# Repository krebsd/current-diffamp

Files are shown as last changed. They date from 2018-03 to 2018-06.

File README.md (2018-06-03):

# Differential current sense Amplifier - current-diffamp

Differential Amplifier circuit for use in current sensing applications. The circuit is designed to be used in conjunction with an oscilloscope.

## PREFACE
This project and especially its documentation including this README is still in a very early state of development. This document will be updated with further information in the future.

## EDA

* [KiCad](http://kicad-pcb.org) - KiCad EDA is used for the PCB design

## Authors

* **David Krebs** - *Initial work* - [krebsd](https://github.com/krebsd)

## License

<br />This work is licensed under a <a rel="license" href="http://creativecommons.org/licenses/by-sa/4.0/">Creative Commons Attribution-ShareAlike 4.0 International License</a>

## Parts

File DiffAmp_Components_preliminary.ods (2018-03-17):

Reference | Value | Part | Part No | Distributor | Distributor Part No
C1 | 10u | C Radial 10 uF 50V D5.0mm_P2.00mm |  | Reichelt | FR-A 10U 50
C2 | 100n | C 0805 100n
C3 | 100u | C Radial 100 uF 50V D8.0mm_P3.50mm |  | Reichelt | RAD FR 100/50
C4 | 100u | C Radial 100 uF 50V D8.0mm_P3.50mm |  | Reichelt | RAD FR 100/50
C5 | 10u | C 1210 X5R 10u 50V | UMK325AB7106MM-T | Digikey | 587-3166-1-ND
C6 | 10u | C 1210 X5R 10u 50V | UMK325AB7106MM-T | Digikey | 587-3166-1-ND
C7 | 10n | C 0805 10n |  | Reichelt
C8 | 10n | C 0805 10n
C9 | 10n | C 0805 10n
C10 | 10n | C 0805 10n
C11 | 10u | C 1210 X5R 10u 50V | UMK325AB7106MM-T | Digikey | 587-3166-1-ND
C12 | 10u | C 1210 X5R 10u 50V | UMK325AB7106MM-T | Digikey | 587-3166-1-ND
C13 | 10n | C 0805 10n
C14 | 100n | C 0805 100n
C15 | C | C 0805
C16 | C | C 0805
C17 | C | C 0805
C18 | C | C 0805
C19 | C | C 0805
C20 | C | C 0805
C21 | C_Variable | Murata TZC3 |  | Reichelt | TZC03 XXP | exact part tbd
C22 | C_Variable | Murata TZC3 |  | Reichelt | TZC03 XXP | exact part tbd
C23 | C | C 0805
C24 | C | C 0805
C25 | C | C 0805
C26 | 100n | C 0805 100n
C27 | 100n | C 0805 100n
C28 | 100n | C 0805 100n
C29 | C | C 0805
C30 | 10p | C 0805 10p
C31 | 100n | C 0805 100n
C32 | 100n | C 0805 100n
C33 | 100n | C 0805 100n
C34 | C | C 0805
C35 | 10p | C 0805 10p
C36 | 100n | C 0805 100n
C37 | 100n | C 0805 100n
C38 | 100n | C 0805 100n
C39 | C | C 0805
D1 | CMPD6001S | CMPD6001S – SOT-23 | CMPD6001S TR | Digikey | CMPD6001SCT-ND
D2 | CMPD6001S | CMPD6001S – SOT-23 | CMPD6001S TR | Digikey | CMPD6001SCT-ND
D3 | CMPD6001S | CMPD6001S – SOT-23 | CMPD6001S TR | Digikey | CMPD6001SCT-ND
D4 | CMPD6001S | CMPD6001S – SOT-23 | CMPD6001S TR | Digikey | CMPD6001SCT-ND
F1 | PFRA050 | Polyfuse PFRA 050 |  | Reichelt | PFRA 050
J1 | USB_OTG | USB Micro B |  | Reichelt | MIC USB BBU
J2 | Screw_Terminal_1x03 | AKL 057-03 |  | Reichelt | AKL 057-03
J3 | Conn_01x02 | Pin Header 1x2 |  | Reichelt
J4 | Conn_01x02 | Pin Header 1x2
J5 | Conn_01x02 | Pin Header 1x2
JP1 | Jumper_NO_Small | Pin Header 1x2
JP2 | Jumper | Pin Header 1x2
JP3 | Jumper_NC_Dual | Pin Header 1x3
JP4 | Jumper | Pin Header 1x2
JP5 | Jumper | Pin Header 1x2
JP6 | Jumper_NC_Dual | Pin Header 1x3
JP7 | Jumper_NC_Dual | Pin Header 1x3
JP8 | Jumper_NO | Pin Header 1x2
R1 | 130k | R 0805 130k 1% |  | Reichelt
R2 | 10k | R 0805 10k 1%
R3 | 10k | R 0805 10k 1%
R4 | 130k | R 0805 130k 1% |  | Reichelt
R5 | 0 | R 0805 0
R6 | 1k | R 0805 1k 1%
R7 | 10k | R 0805 10k 1%
R8 | 10k | R 0805 10k 1%
R9 | 22 | R 0805 22 1%
R10 | Y14870R10000B9W | CSM2512 – 0R1 0,1% | Y14870R10000B9W | Digikey | Y1487-.1-ND
R11 | 3M9 | R 0805 3M9 0,1% |  | Reichelt |  | Testing with 1%!
R12 | 3M9 | R 0805 3M9 0,1% |  | Reichelt |  | Testing with 1%!
R13 | 3M9 | R 0805 3M9 0,1% |  | Reichelt |  | Testing with 1%!
R14 | 3M9 | R 0805 3M9 0,1% |  | Reichelt |  | Testing with 1%!
R15 | 1M2 | R 0805 1M2 0,1% |  | Reichelt |  | Testing with 1%!
R16 | 1M2 | R 0805 1M2 0,1% |  | Reichelt |  | Testing with 1%!
R17 | 1M0 | R 0805 1M0 0,1% |  | Reichelt |  | Testing with 1%!
R18 | 1M0 | R 0805 1M0 0,1% |  | Reichelt |  | Testing with 1%!
R19 | 249 | R 0805 249 1% |  | Reichelt
R20 | 249 | R 0805 249 1% |  | Reichelt
R21 | 249 | R 0805 249 1% |  | Reichelt
R22 | 249 | R 0805 249 1% |  | Reichelt
R23 | 249 | R 0805 249 1% |  | Reichelt
R24 | 249 | R 0805 249 1% |  | Reichelt
R25 | 249 | R 0805 249 1% |  | Reichelt
R26 | 249 | R 0805 249 1% |  | Reichelt
R27 | 100 | R 0805 100 0,05% | RG2012N-101-W-T1 | Digikey | RG20N100WCT-ND
R28 | 1k | R 0805 1k 0,05% | ERA-6ARW102V | Digikey | P1.0KBSCT-ND
R29 | 0 | R 0805 0
R30 | 47 | R 2512 47 | RC2512JK-0747RL | Digikey | YAG3404CT-ND
R31 | R | R 0805
R32 | 1k0 | R 0805 1k 0,05% | ERA-6ARW102V | Digikey | P1.0KBSCT-ND
R33 | 6k8 | R 0805 6k8 0,05% | ERA-6ARW682V | Digikey | P6.8KBSCT-ND
R34 | 0 | R 0805 0
R35 | 2k2 | R 0805 2k2 0,05% | ERA-6ARW222V | Digikey | P2.2KBSCT-ND
R36 | 47 | R 2512 47 | RC2512JK-0747RL | Digikey | YAG3404CT-ND
R37 | R | R 0805
R38 | 1k0 | R 0805 1k 0,05% | ERA-6ARW102V | Digikey | P1.0KBSCT-ND
R39 | 6k8 | R 0805 6k8 0,05% | ERA-6ARW682V | Digikey | P6.8KBSCT-ND
R40 | 0 | R 0805 0
R41 | 2k2 | R 0805 2k2 0,05% | ERA-6ARW222V | Digikey | P2.2KBSCT-ND
R42 | 47 | R 2512 47 | RC2512JK-0747RL | Digikey | YAG3404CT-ND
R43 | R | R 0805
U1 | SF_IHXXXXS | DC DC Converter SF IH0524S | IH0524SH | Digikey | 1470-1446-5-ND
U2 | TPS7A49 | Linear Regulator positive TPS7A49 |  | Reichelt | TPS 7A4901DGNT
U3 | TPS7A30 | Linear Regulator negative TPS7A30 |  | Reichelt | TPS 7A3001DGNT
U4 | OPA189 | OPAmp OPA189 | OPA189ID | Digikey | 296-47522-ND
U5 | AD8421 | Differential Amplifier AD8421BRZ | AD8421BRZ | Digikey | AD8421BRZ-R7CT-ND
U6 | OPA189 | OPAmp OPA189 | OPA189ID | Digikey | 296-47522-ND
U7 | OPA189 | OPAmp OPA189 | OPA189ID | Digikey | 296-47522-ND

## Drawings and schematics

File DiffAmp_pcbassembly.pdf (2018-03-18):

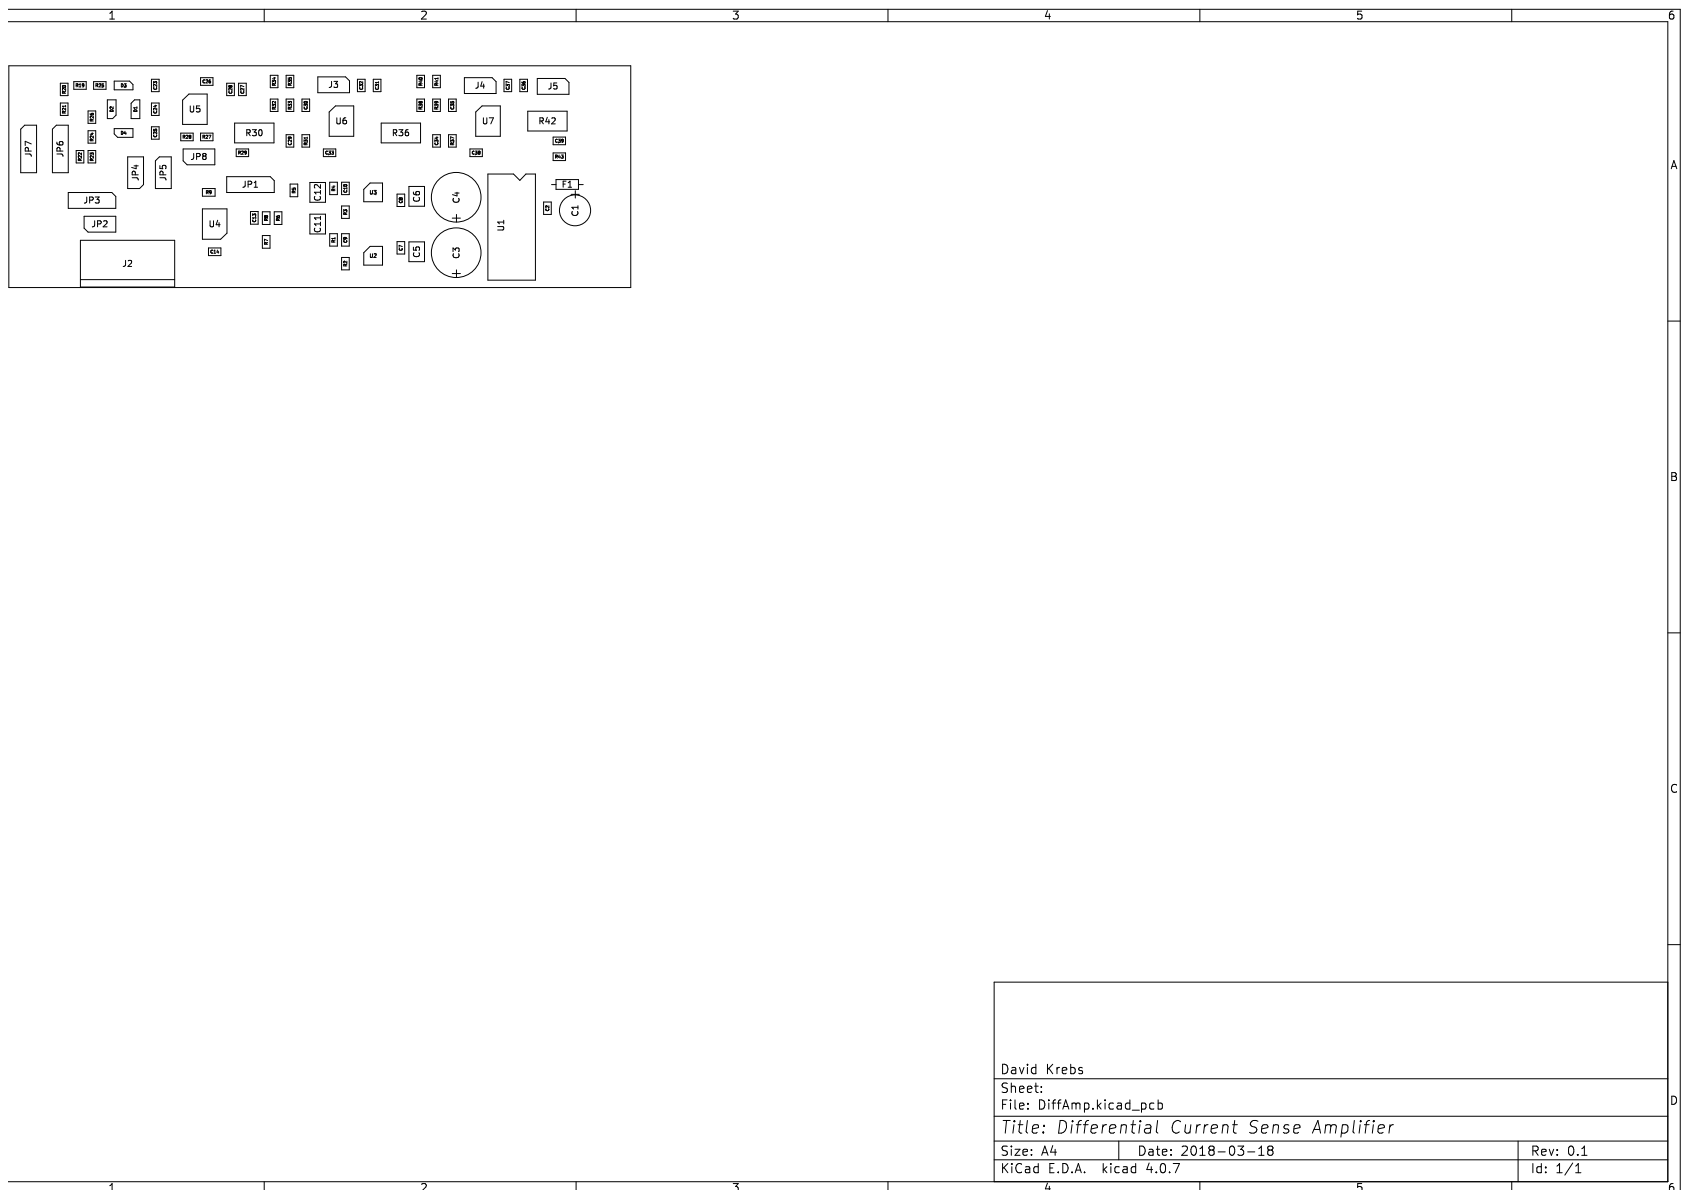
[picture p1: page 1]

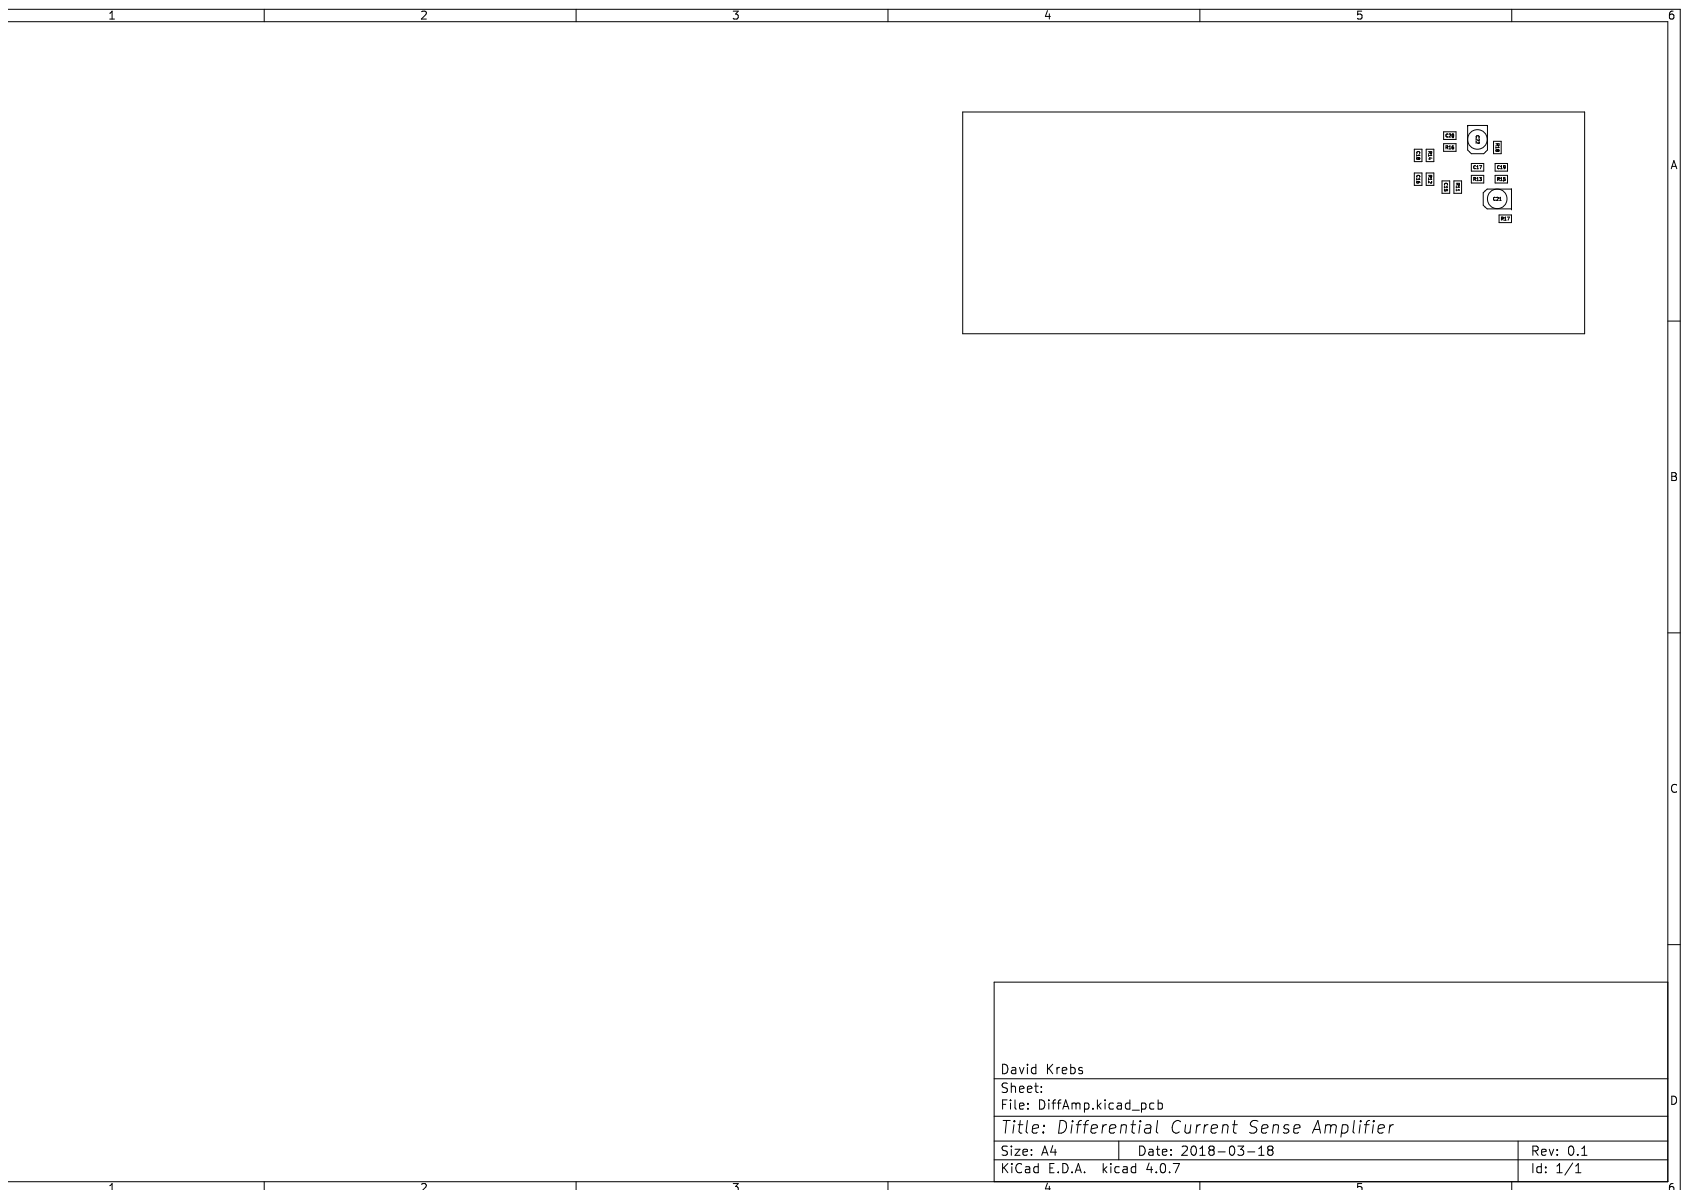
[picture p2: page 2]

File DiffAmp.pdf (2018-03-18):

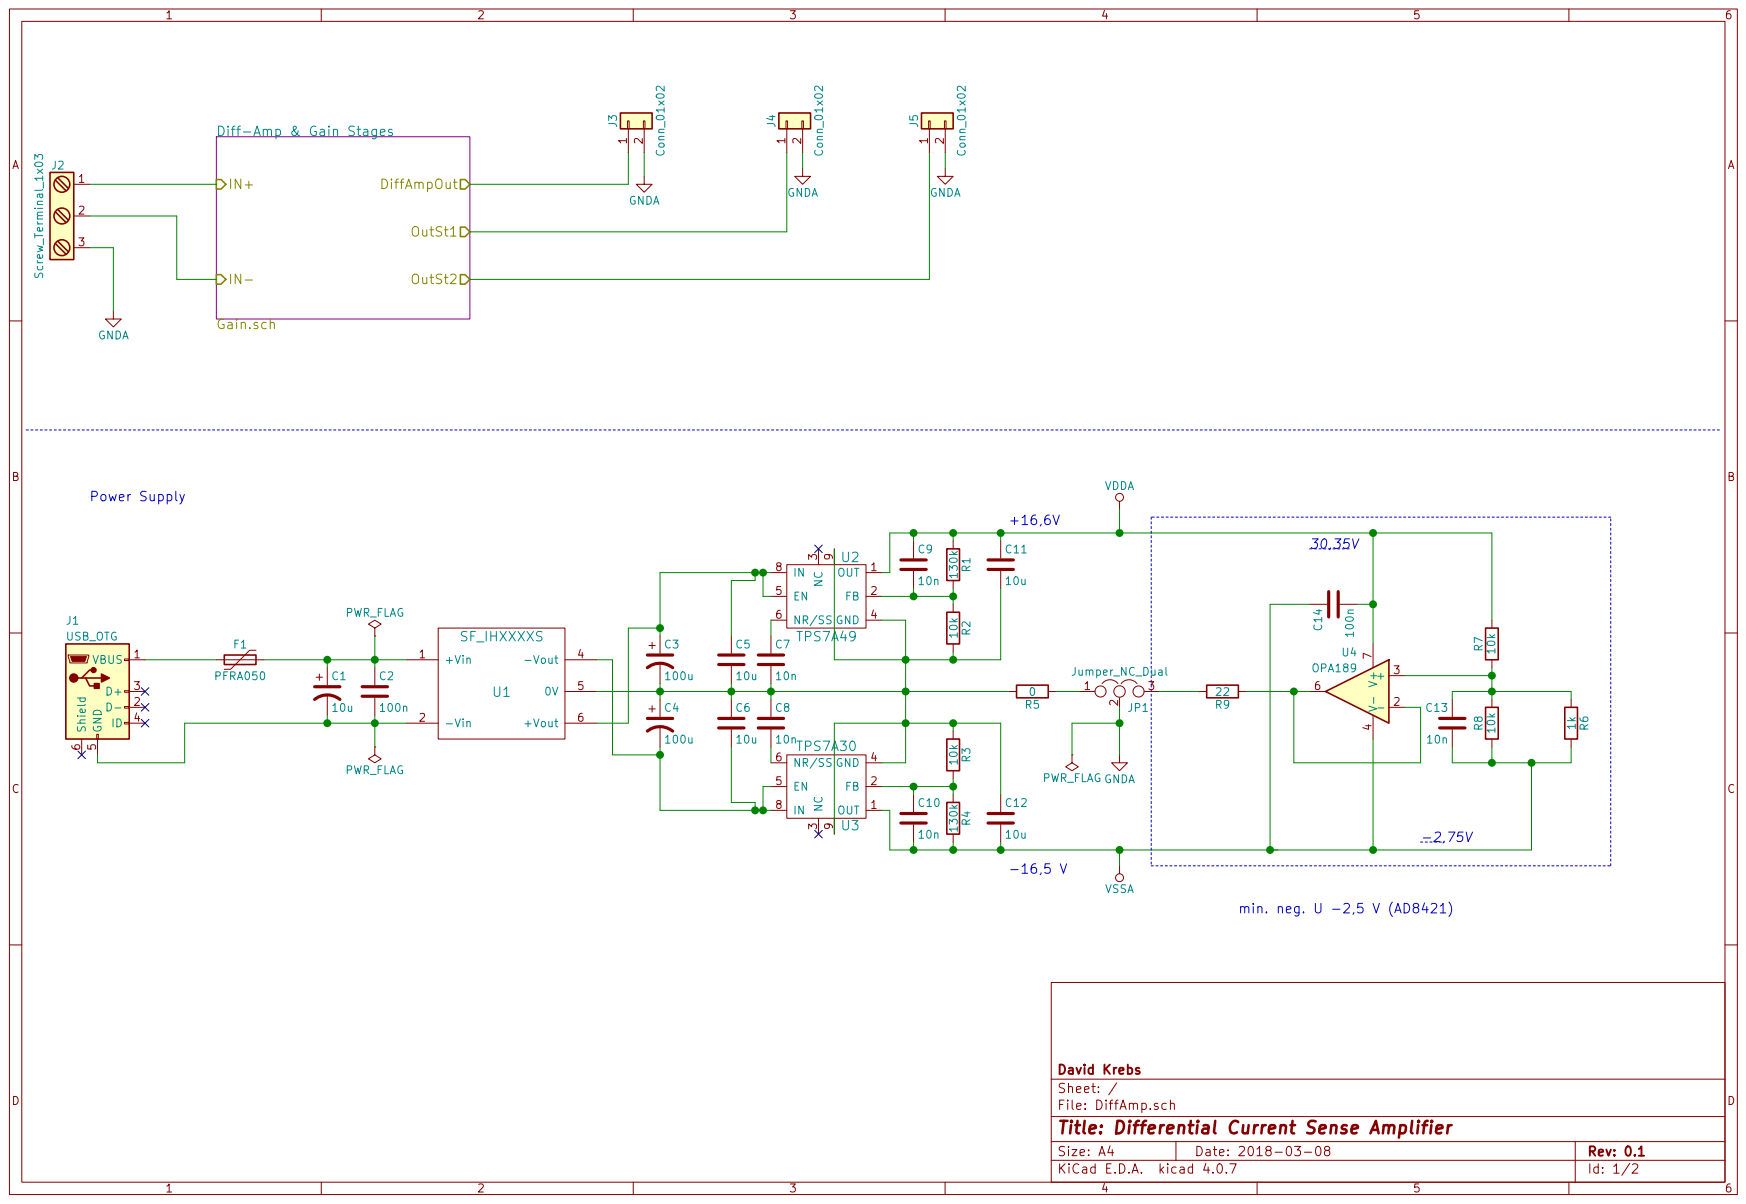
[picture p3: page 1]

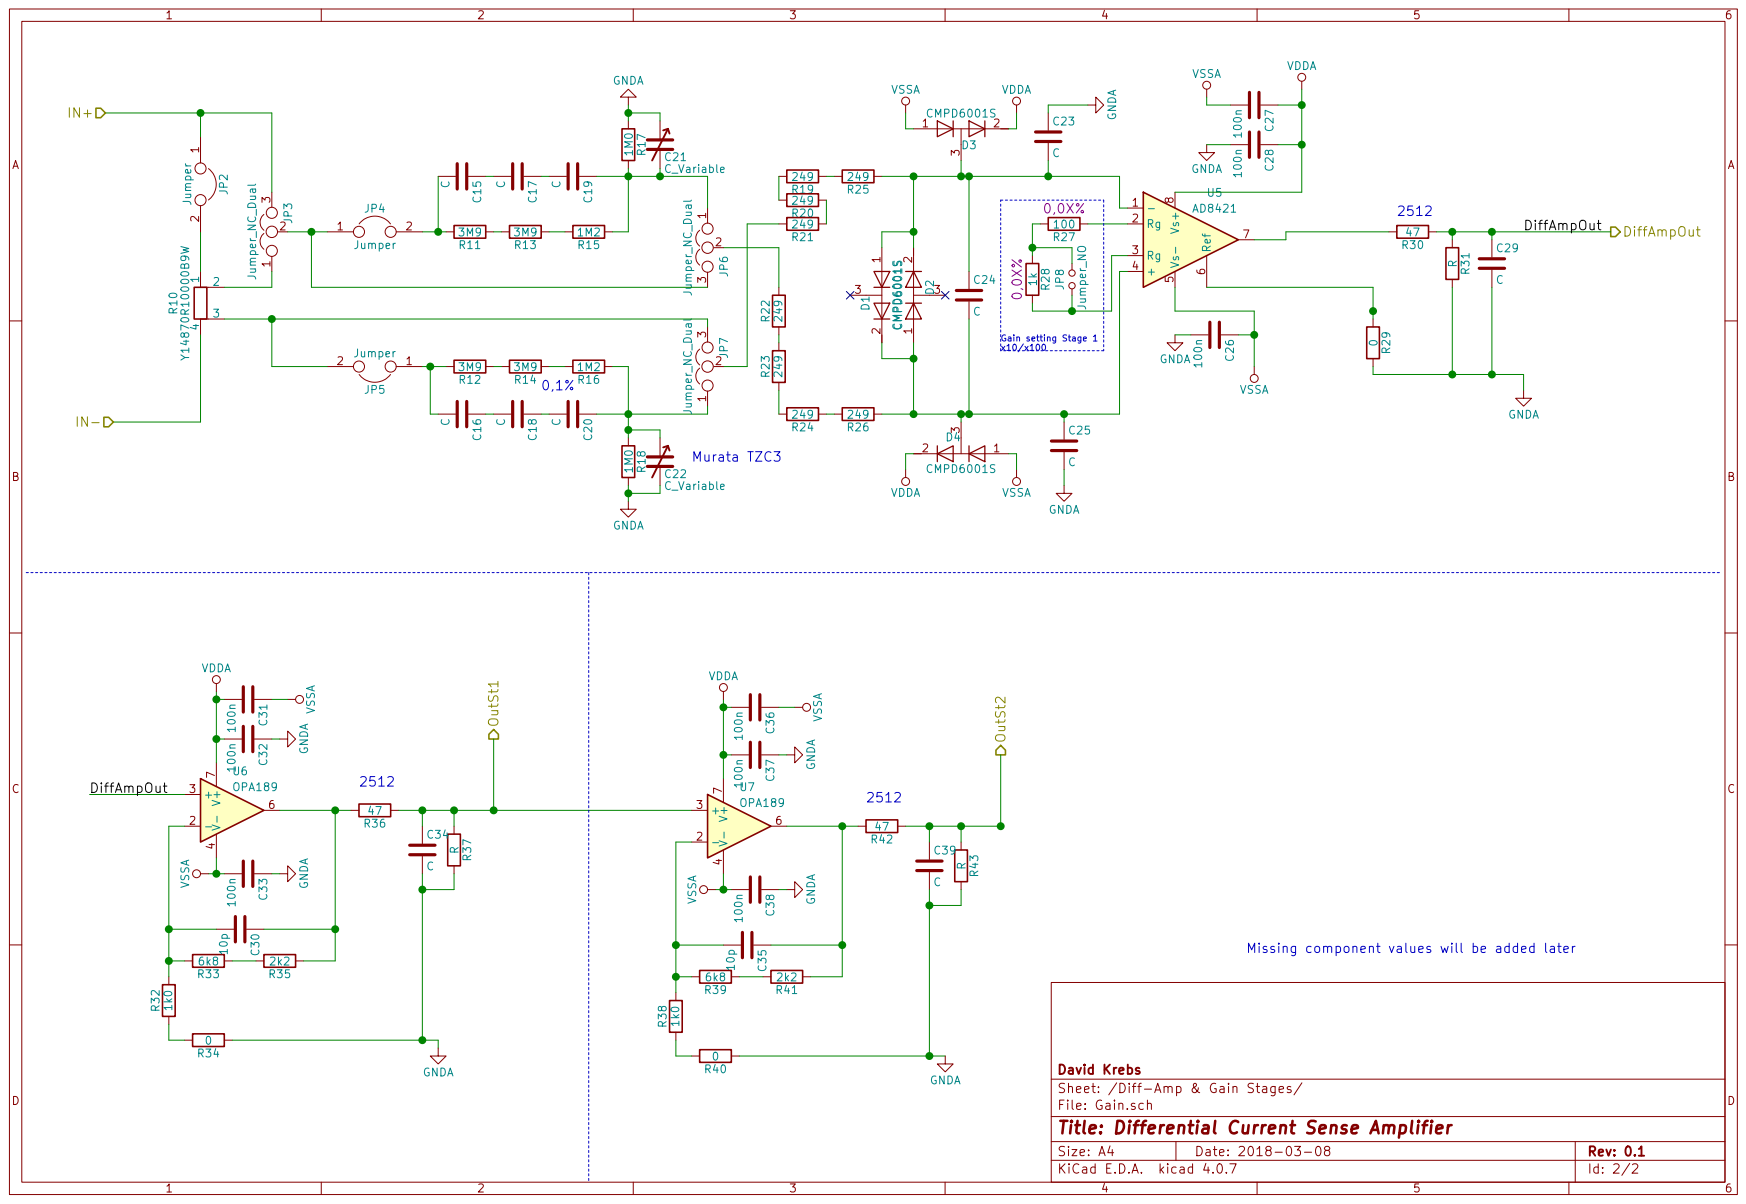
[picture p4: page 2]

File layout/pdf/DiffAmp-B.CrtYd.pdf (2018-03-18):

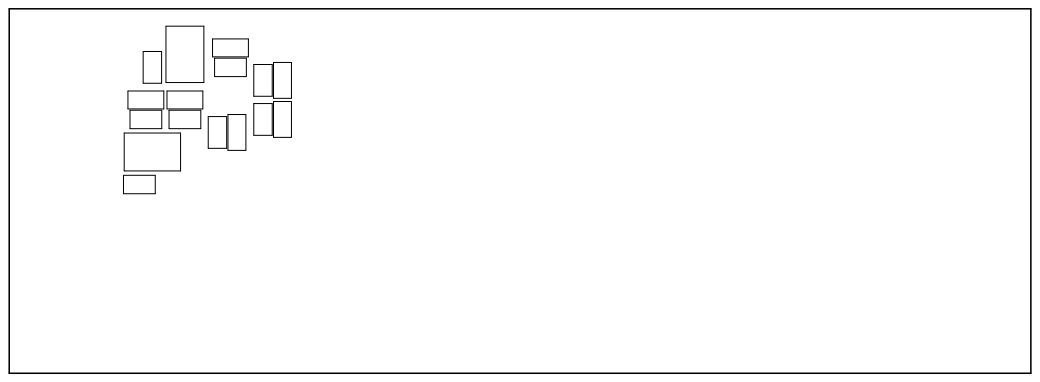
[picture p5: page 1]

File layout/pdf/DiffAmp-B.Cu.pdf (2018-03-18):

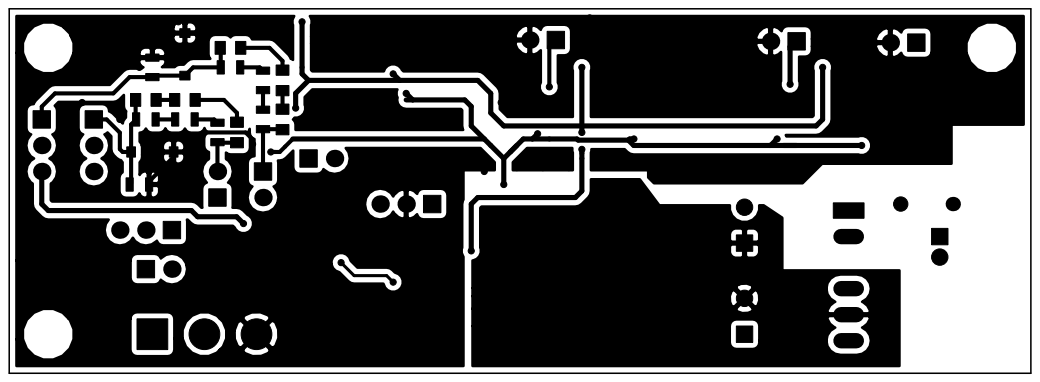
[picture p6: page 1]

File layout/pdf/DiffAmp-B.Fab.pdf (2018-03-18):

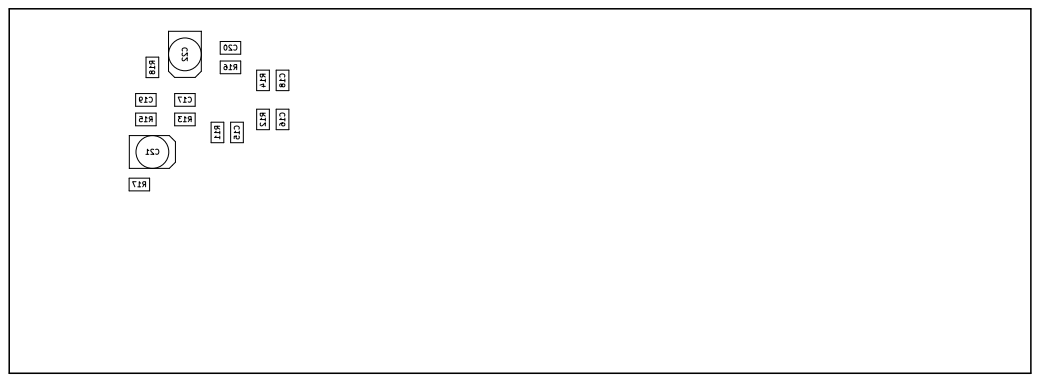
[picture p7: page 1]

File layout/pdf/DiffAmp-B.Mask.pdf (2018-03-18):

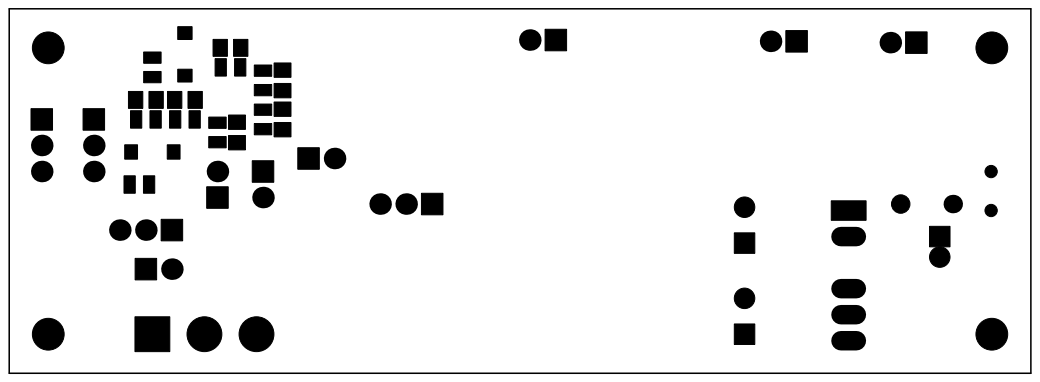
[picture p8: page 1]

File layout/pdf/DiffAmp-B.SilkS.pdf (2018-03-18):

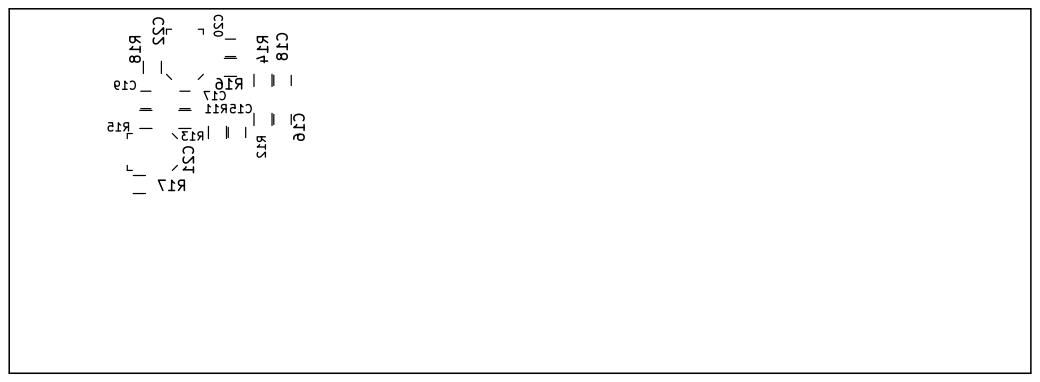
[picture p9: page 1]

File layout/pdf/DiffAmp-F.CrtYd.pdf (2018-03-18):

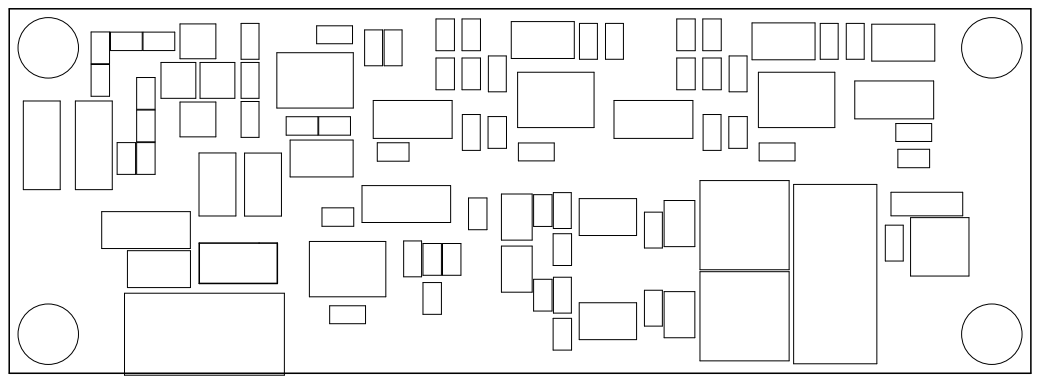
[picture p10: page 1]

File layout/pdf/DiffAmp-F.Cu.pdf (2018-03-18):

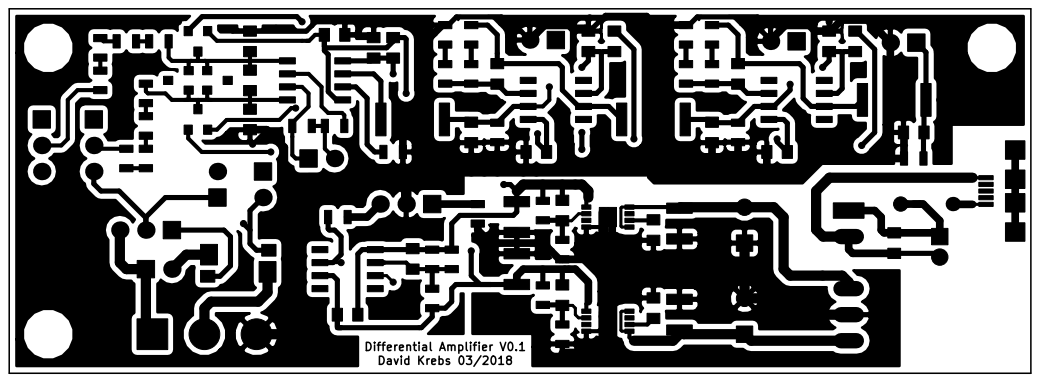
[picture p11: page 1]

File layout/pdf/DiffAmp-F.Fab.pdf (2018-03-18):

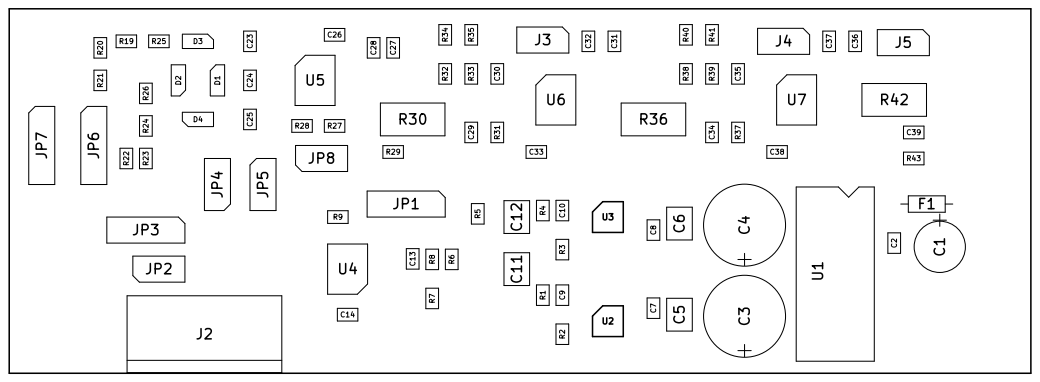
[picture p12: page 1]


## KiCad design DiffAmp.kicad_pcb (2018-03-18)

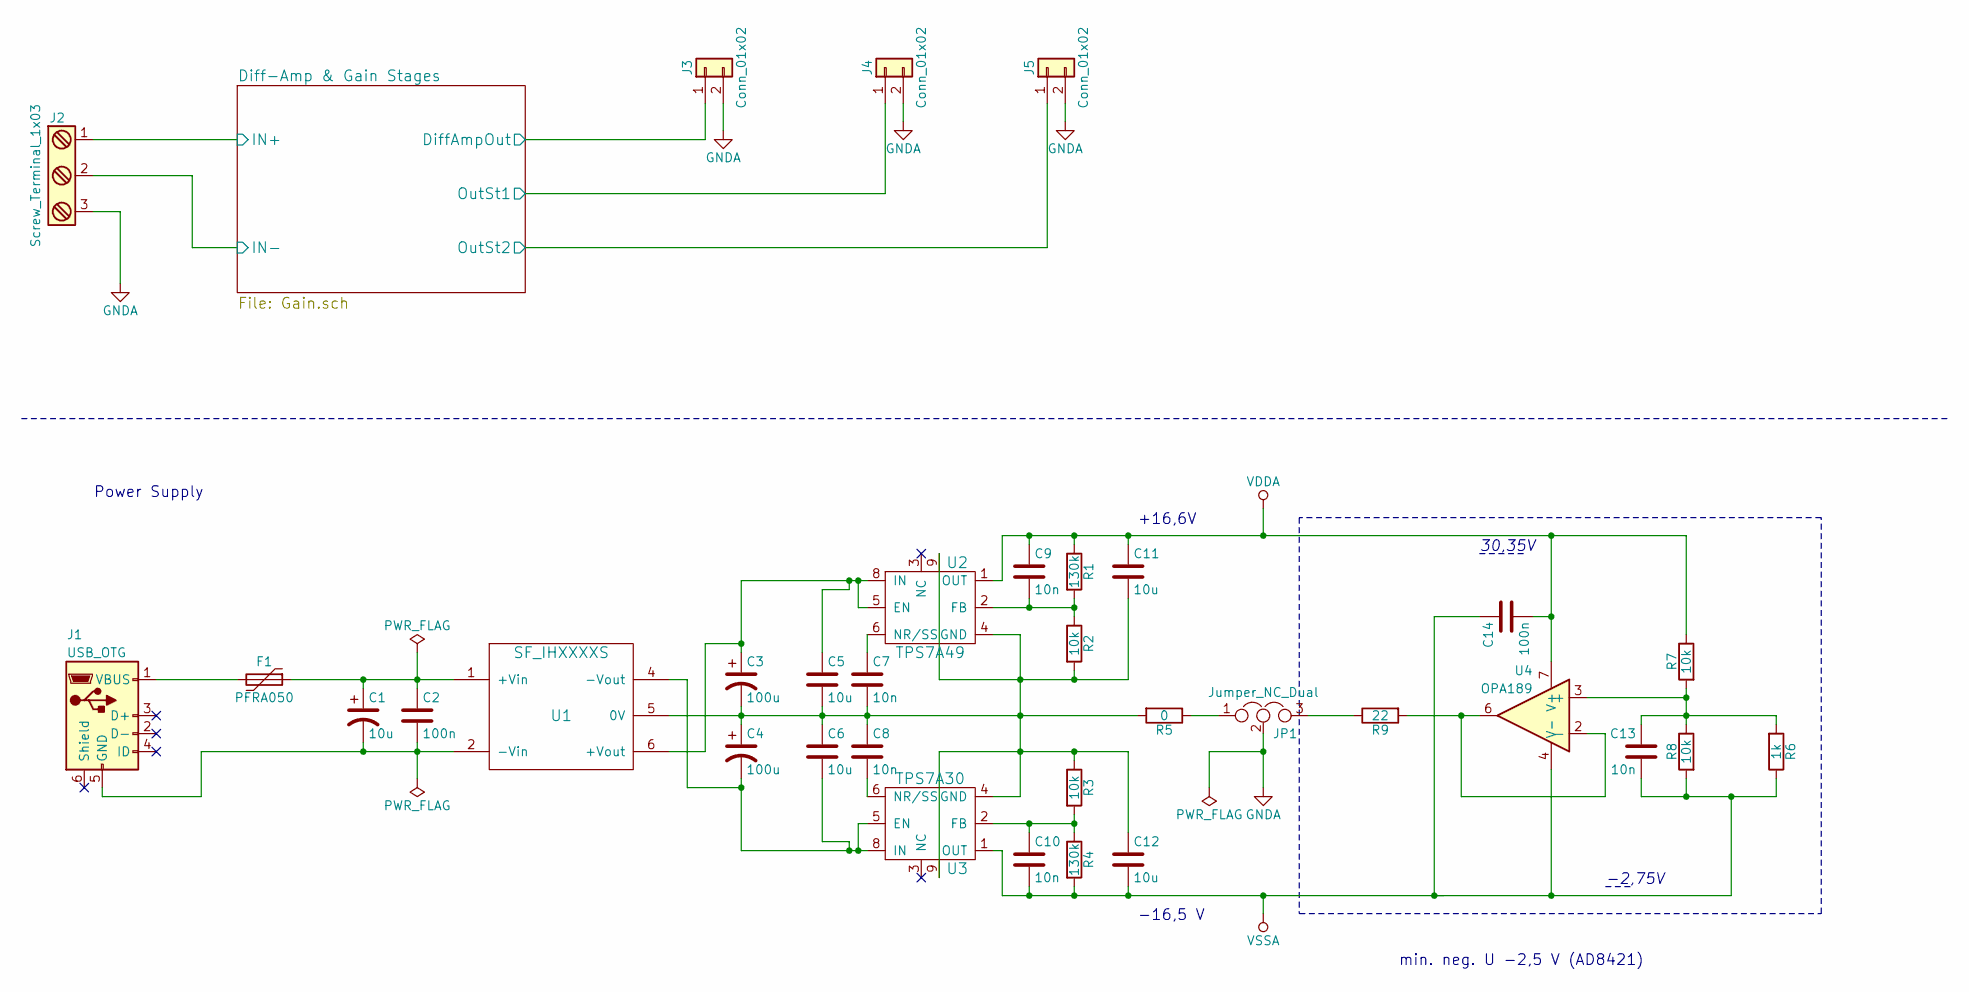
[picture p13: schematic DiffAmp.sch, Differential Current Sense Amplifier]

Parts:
C1: 10u; CP_Radial_D5.0mm_P2.00mm
C2, C14: 100n; C_0805
C3, C4: 100u; CP_Radial_D8.0mm_P3.50mm
C5, C6, C11, C12: 10u; C_1210
C7, C8, C9, C10, C13: 10n; C_0805
F1: PFRA050; R_Axial_DIN0204_L3.6mm_D1.6mm_P5.08mm_Horizontal
J1: USB_OTG; MIC_USB_BBU
J2: Screw_Terminal_1x03; TerminalBlock_bornier-3_P5.08mm
J3, J4, J5: Conn_01x02; Pin_Header_Straight_1x02_Pitch2.54mm
JP1: Jumper_NC_Dual; Pin_Header_Straight_1x03_Pitch2.54mm
R1, R4: 130k; R_0805
R2, R3, R7, R8: 10k; R_0805
R5: 0; R_0805
R6: 1k; R_0805
R9: 22; R_0805
U1: SF_IHXXXXS; DCDC-Conv_TRACO_TMR_1-xxxx_Dual
U2: TPS7A49; MSOP-8-1EP_3x3mm_Pitch0.65mm
U3: TPS7A30; MSOP-8-1EP_3x3mm_Pitch0.65mm
U4: OPA189; SOIC-8_3.9x4.9mm_Pitch1.27mm

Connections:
/Diff-Amp & Gain Stages/DiffAmpOut: J3.1; also elsewhere on the board
/Diff-Amp & Gain Stages/IN+: J2.1; also elsewhere on the board
/Diff-Amp & Gain Stages/IN-: J2.2; also elsewhere on the board
/Diff-Amp & Gain Stages/OutSt1: J4.1; also elsewhere on the board
/Diff-Amp & Gain Stages/OutSt2: J5.1; also elsewhere on the board
GNDA: J2.3, J3.2, J4.2, J5.2, JP1.2; also elsewhere on the board
unnamed: C1.1, C2.1, F1.1, U1.1 (+Vin)
unnamed: C1.2, C2.2, J1.5 (GND), U1.2 (-Vin)
unnamed: C3.1, C5.1, U1.6 (+Vout), U2.5 (EN), U2.8 (IN)
unnamed: C4.2, C6.2, U1.4 (-Vout), U3.5 (EN), U3.8 (IN)
unnamed: C7.1, U2.6 (NR/SS)
unnamed: C8.2, U3.6 (NR/SS)
unnamed: C9.2, R1.2, R2.1, U2.2 (FB)
unnamed: C10.1, R3.2, R4.1, U3.2 (FB)
unnamed: C3.2, C4.1, C5.2, C6.1, C7.2, C8.1, C11.2, C12.1, R2.2, R3.1, R5.2, U1.5 (0V), U2.4 (GND), U2.9, U3.4 (GND), U3.9
unnamed: C13.1, R6.2, R7.2, R8.1, U4.3 (+)
unnamed: F1.2, J1.1 (VBUS)
unnamed: JP1.1, R5.1
unnamed: JP1.3, R9.1
unnamed: R9.2, U4.2 (-), U4.6
VDDA: C9.1, C11.1, C14.2, R1.1, R7.1, U2.1 (OUT), U4.7 (V+); also elsewhere on the board
VSSA: C10.2, C12.2, C13.2, C14.1, R4.2, R6.1, R8.2, U3.1 (OUT), U4.4 (V-); also elsewhere on the board

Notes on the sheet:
-16,5 V
+16,6V
-2,75V
30,35V
min. neg. U -2,5 V (AD8421)
Power Supply

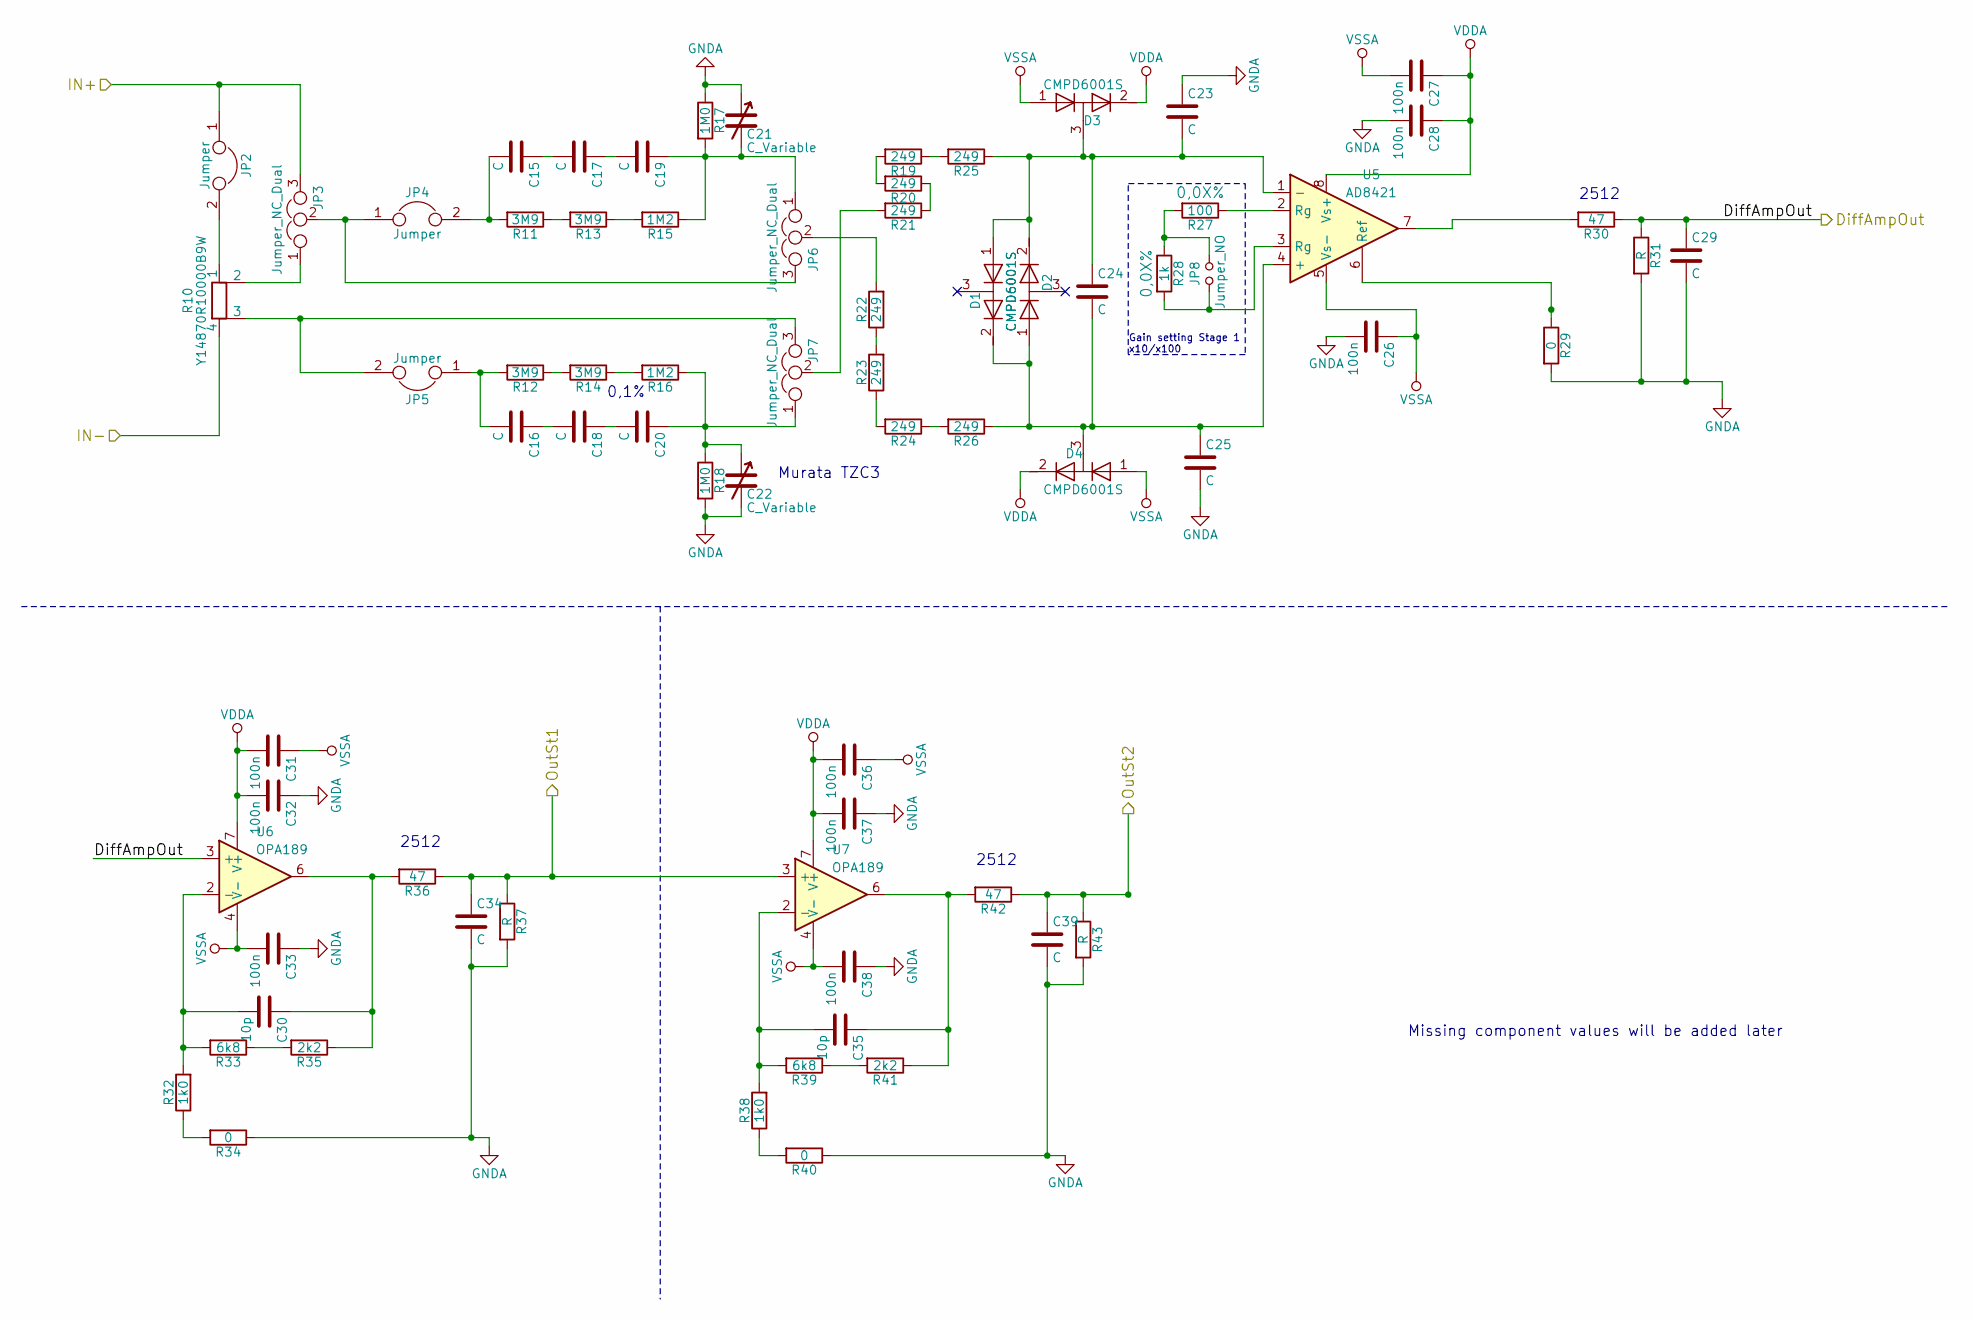
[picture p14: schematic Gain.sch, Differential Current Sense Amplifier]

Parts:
C15, C16, C17, C18, C19, C20, C23, C24, C25, C29, C34, C39: C; C_0805
C21, C22: C_Variable; C_Trimmer_Murata_TZC3
C26, C27, C28, C31, C32, C33, C36, C37, C38: 100n; C_0805
C30, C35: 10p; C_0805
D1, D2, D3, D4: CMPD6001S; SOT-23
JP2, JP4, JP5: Jumper; Pin_Header_Straight_1x02_Pitch2.54mm
JP3, JP6, JP7: Jumper_NC_Dual; Pin_Header_Straight_1x03_Pitch2.54mm
JP8: Jumper_NO; Pin_Header_Straight_1x02_Pitch2.54mm
R10: Y14870R10000B9W; CSM2512
R11, R12, R13, R14: 3M9; R_0805
R15, R16: 1M2; R_0805
R17, R18: 1M0; R_0805
R19, R20, R21, R22, R23, R24, R25, R26: 249; R_0805
R27: 100; R_0805; Toleranz 0,0X%
R28: 1k; R_0805; Toleranz 0,0X%
R29, R34, R40: 0; R_0805
R30, R36, R42: 47; R_2512
R31, R37, R43: R; R_0805
R32, R38: 1k0; R_0805
R33, R39: 6k8; R_0805
R35, R41: 2k2; R_0805
U5: AD8421; SOIC-8_3.9x4.9mm_Pitch1.27mm
U6, U7: OPA189; SOIC-8_3.9x4.9mm_Pitch1.27mm

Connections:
/Diff-Amp & Gain Stages/DiffAmpOut: C29.1, R30.1, R31.1, U6.3 (+); also elsewhere on the board
/Diff-Amp & Gain Stages/IN+: JP2.1, JP3.3; also elsewhere on the board
/Diff-Amp & Gain Stages/IN-: R10.4; also elsewhere on the board
/Diff-Amp & Gain Stages/OutSt1: C34.1, R36.1, R37.1, U7.3 (+); also elsewhere on the board
/Diff-Amp & Gain Stages/OutSt2: C39.1, R42.1, R43.1; also elsewhere on the board
GNDA: C21.1, C22.2, C23.1, C25.2, C26.2, C28.2, C29.2, C32.1, C33.1, C34.2, C37.1, C38.1, C39.2, R17.1, R18.2, R29.2, R31.2, R34.1, R37.2, R40.1, R43.2; also elsewhere on the board
unnamed: C15.1, C17.2
unnamed: C15.2, JP4.2, R11.2
unnamed: C16.1, C18.2
unnamed: C16.2, JP5.1, R12.2
unnamed: C17.1, C19.2
unnamed: C18.1, C20.2
unnamed: C19.1, C21.2, JP6.1, R15.1, R17.2
unnamed: C20.1, C22.1, JP7.1, R16.1, R18.1
unnamed: C23.2, C24.1, D1.1 (A), D2.2 (K), D3.3 (common), R25.1, U5.1 (-)
unnamed: C24.2, C25.1, D1.2 (K), D2.1 (A), D4.3 (common), R26.1, U5.4 (+)
unnamed: C30.1, R35.1, R36.2, U6.6
unnamed: C30.2, R32.2, R33.2, U6.2 (-)
unnamed: C35.1, R41.1, R42.2, U7.6
unnamed: C35.2, R38.2, R39.2, U7.2 (-)
unnamed: JP2.2, R10.1
unnamed: JP3.1, R10.2
unnamed: JP3.2, JP4.1, JP6.3
unnamed: JP5.2, JP7.3, R10.3
unnamed: JP6.2, R22.2
unnamed: JP7.2, R21.2
unnamed: JP8.1, R28.2, U5.3 (Rg)
unnamed: JP8.2, R27.2, R28.1
unnamed: R11.1, R13.2
unnamed: R12.1, R14.2
unnamed: R13.1, R15.2
unnamed: R14.1, R16.2
unnamed: R19.1, R25.2
unnamed: R19.2, R20.2
unnamed: R20.1, R21.1
unnamed: R22.1, R23.2
unnamed: R23.1, R24.2
unnamed: R24.1, R26.2
unnamed: R27.1, U5.2 (Rg)
unnamed: R29.1, U5.6 (Ref)
unnamed: R30.2, U5.7
unnamed: R32.1, R34.2
unnamed: R33.1, R35.2
unnamed: R38.1, R40.2
unnamed: R39.1, R41.2
VDDA: C27.1, C28.1, C31.2, C32.2, C36.2, C37.2, D3.2 (K), D4.2 (K), U5.8 (Vs+), U6.7 (V+), U7.7 (V+); also elsewhere on the board
VSSA: C26.1, C27.2, C31.1, C33.2, C36.1, C38.2, D3.1 (A), D4.1 (A), U5.5 (Vs-), U6.4 (V-), U7.4 (V-); also elsewhere on the board

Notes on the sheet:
0,1%
2512
Gain setting Stage 1 x10/x100
Missing component values will be added later
Murata TZC3

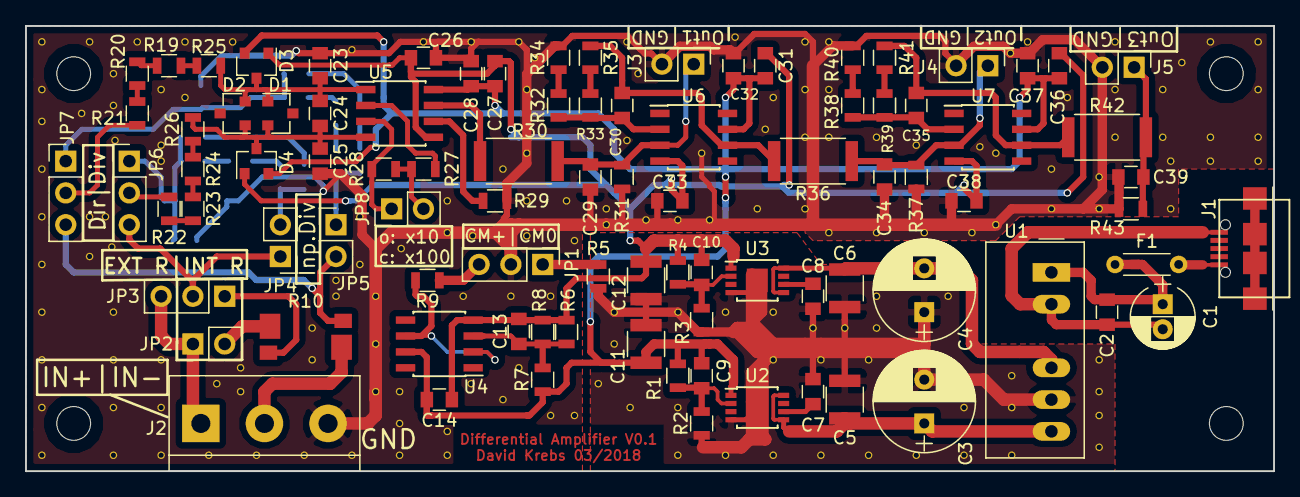
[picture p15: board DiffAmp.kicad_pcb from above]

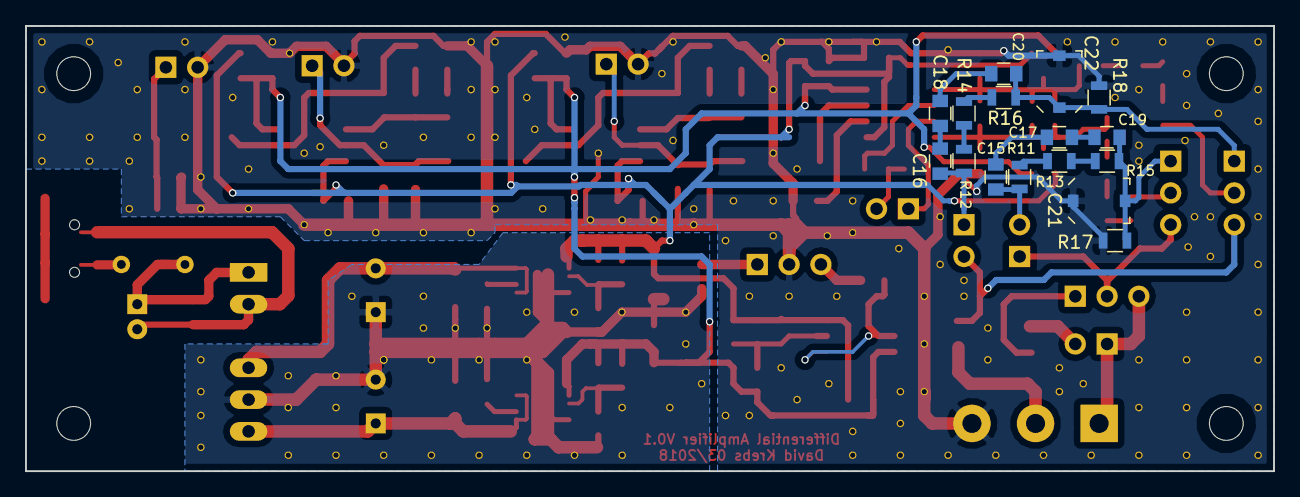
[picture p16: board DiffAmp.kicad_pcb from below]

Board: 2 copper layers, 99.7 x 35.6 mm, 107 parts (16 on the bottom side), 61 nets.

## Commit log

2018-03-14 Initial state of schematic
    [DiffAmp.sch, Gain.sch]
2018-03-16 Schematic rearranged Added Netlist
    [DiffAmp.sch, Gain.sch]
2018-03-16 Parts placed on PCB
    [DiffAmp.kicad_pcb, DiffAmp.sch]
2018-03-16 Corrected Board Outline
    [DiffAmp.kicad_pcb]
2018-03-16 Begin Layouting
    [DiffAmp.kicad_pcb, DiffAmp.sch]
2018-03-17 Layout Completed
    [DiffAmp.kicad_pcb]
2018-03-17 Silkscreen corrected
    [DiffAmp.kicad_pcb]
2018-03-17 Schematic pdf, Layout pdf + Gerber added
    [DiffAmp-B.Cu.gbr, DiffAmp-B.Mask.gbr, DiffAmp-B.SilkS.gbr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]
2018-03-17 Added preliminary component list
    [DiffAmp_Components_preliminary.ods]
2018-03-18 Added PCB Assembly Drawing
    [DiffAmp.kicad_pcb]
2018-03-18 saved project footprints
2018-03-18 Changed GNDA-"Generation" on Schematic and Board
    [DiffAmp-B.Cu.gbr, DiffAmp-B.Mask.gbr, DiffAmp-B.SilkS.gbr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]
2018-03-18 Small modifications to layout - GND-Plane, VDD/VSS routing
    [DiffAmp-B.Cu.gbr, DiffAmp-B.Mask.gbr, DiffAmp-B.SilkS.gbr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]
